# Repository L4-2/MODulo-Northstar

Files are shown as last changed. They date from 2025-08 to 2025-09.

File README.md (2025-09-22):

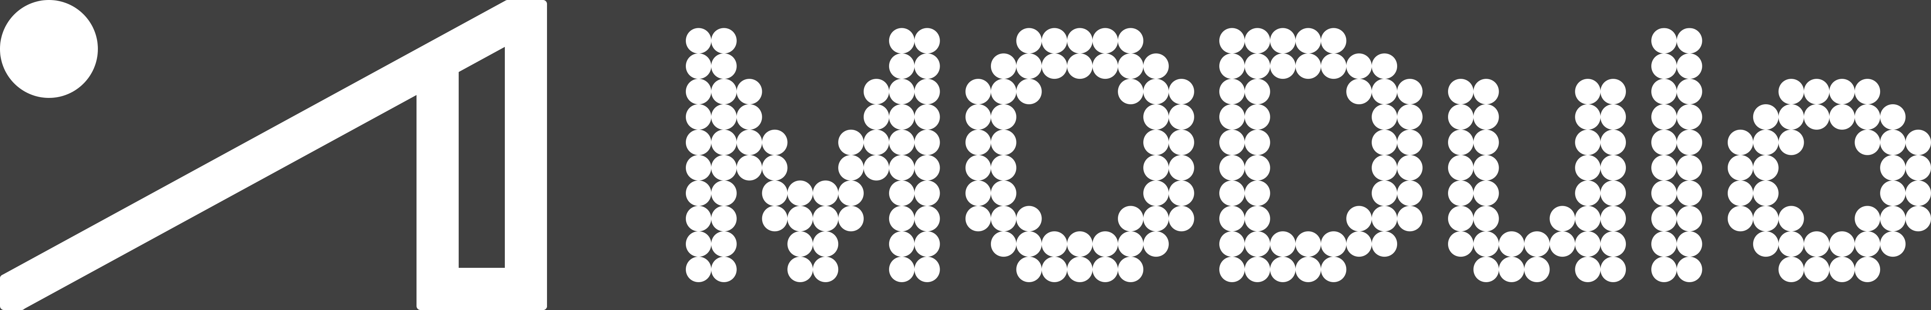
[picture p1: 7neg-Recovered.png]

##

## Authors

- [@L42](https://www.github.com/L4-2)

## License


# Northstar

This is the MODulo mouse development board. The Kicad project files are for Kicad 9.0 and above. You are free to use this design for your own use (non-commercial) as long as you credit here in some way.

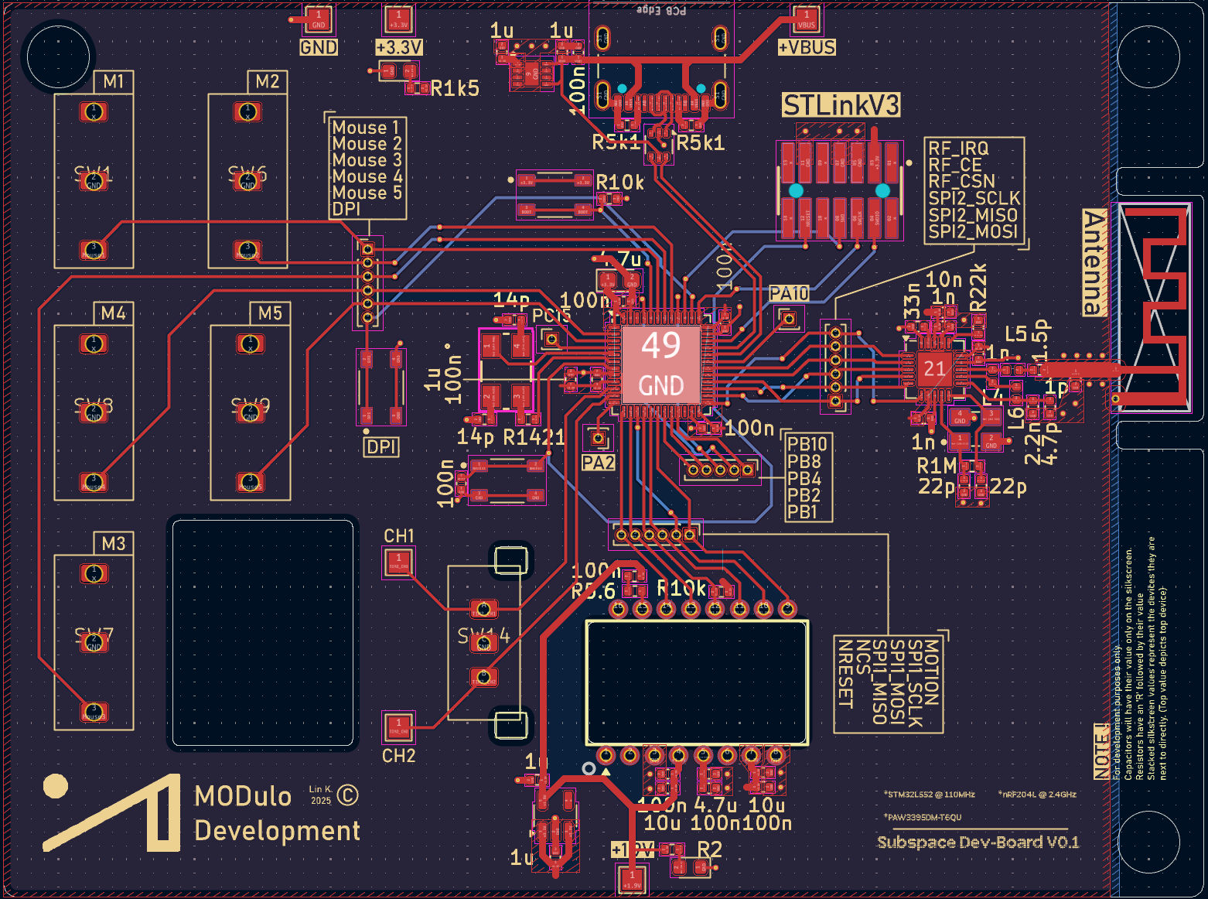
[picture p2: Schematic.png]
PCB


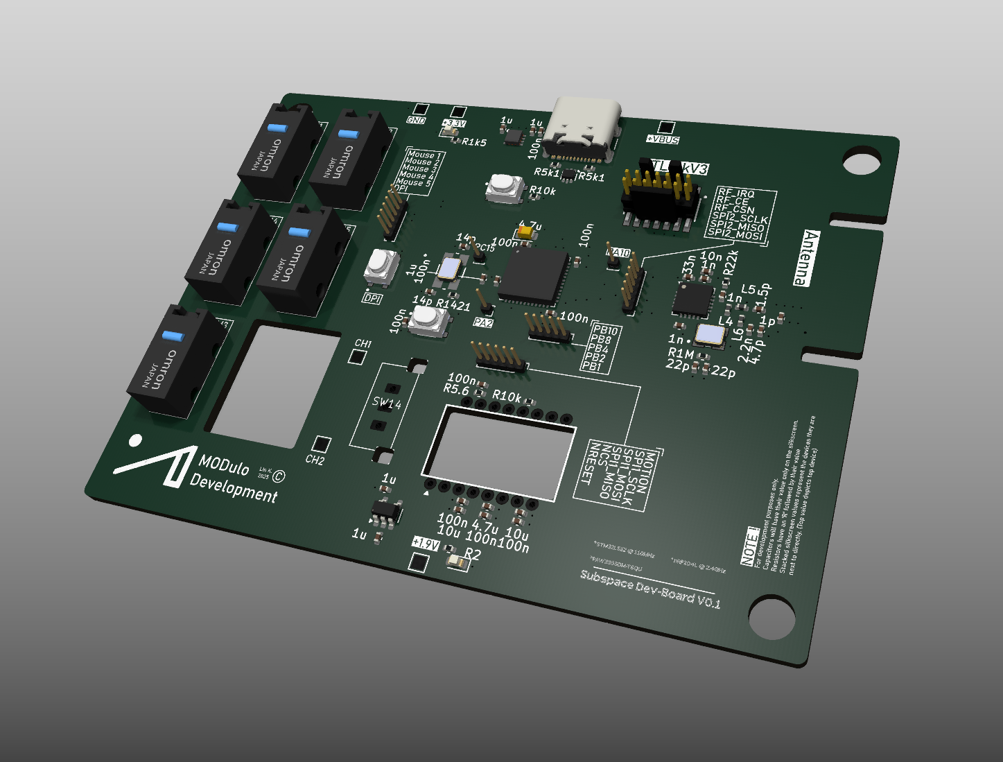
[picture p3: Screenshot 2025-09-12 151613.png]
3D Render


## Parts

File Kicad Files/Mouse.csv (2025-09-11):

Part Number* | Reference | Value | Datasheet | Footprint | Qty | DNP
CBR04C109C5GAC | C67 | 1p | ~ | Capacitor_SMD:C_0402_1005Metric | 1
CBR04C159C5GAC | C66 | 1.5p | ~ | Capacitor_SMD:C_0402_1005Metric | 1
CBR04C479C5GAC | C71 | 4.7p | ~ | Capacitor_SMD:C_0402_1005Metric | 1
04025U140FAT2A | C76,C78 | 14p | ~ | Capacitor_SMD:C_0402_1005Metric | 2
C0402C220K5GACTU | C61,C62 | 22p | ~ | Capacitor_SMD:C_0402_1005Metric | 2
C0402C102J5RACTU | C52,C54,C55 | 1n | ~ | Capacitor_SMD:C_0402_1005Metric | 3
C0402C222J5RACTUl | C70 | 2.2n | ~ | Capacitor_SMD:C_0402_1005Metric | 1
CHQ02-2N7J-RC | L6 | 2.7n | ~ | Inductor_SMD:L_0402_1005Metric | 1
WB0402T3N9SJ | L5 | 3.9n | ~ | Inductor_SMD:L_0402_1005Metric | 1
WB0402T8N2SJ | L4 | 8.2n | ~ | Inductor_SMD:L_0402_1005Metric | 1
C0402C103J3RACTU | C49 | 10n | ~ | Capacitor_SMD:C_0402_1005Metric | 1
C0402C333J4RACTU | C57 | 33n | ~ | Capacitor_SMD:C_0402_1005Metric | 1
C0402C104K4PACTU | C53,C58,C60,C65,C74,C75,C79,C80,C81,C82,C84,C89,C90,C91,C92 | 100n | ~ | Capacitor_SMD:C_0402_1005Metric | 15
GRM155R61E105KA12D | C8,C12,C15,C68,C83 | 1u | ~ | Capacitor_SMD:C_0402_1005Metric | 5
CC0402MRX5R6BB475,T491C106K016AT7280 | C59,C77 | 4.7u | ~ | Capacitor_SMD:C_0402_1005Metric,Capacitor_Tantalum_SMD:CP_EIA-2012-12_Kemet-R | 2
KAM05CT70E106KH | C56,C63 | 10u | ~ | Capacitor_SMD:C_0402_1005Metric | 2
AC0402FR-075R6L | R31 | 5.6 | ~ | Resistor_SMD:R_0402_1005Metric | 1
RN73R1ETTP1421B25 | R35 | 1421 | ~ | Resistor_SMD:R_0402_1005Metric | 1
RT0402BRE0710KL | R32,R36 | 10k | ~ | Resistor_SMD:R_0402_1005Metric | 2
ERA-2AEB223X | R20 | 22k | ~ | Resistor_SMD:R_0402_1005Metric | 1
RE0402BRE071ML | R27 | 1M | ~ | Resistor_SMD:R_0402_1005Metric | 1
ERA-2AEB512X | R41,R42 | 5k1 | ~ | Resistor_SMD:R_0402_1005Metric | 2
ECS-160-12-33Q-JES-TR | Y1 | ECS-160-12-33Q-JES-TR |  | ECS_160_12_33Q_JES_TR:XTAL_ECS-160-12-33Q-JES-TR | 1
ECS-80-12-30BQ-JES-TR | XTAL2 | ECS-80-12-30BQ-JES-TR | ECS-80-12-30BQ-JES-TR | ECS-80-12-30BQ-JES-TR:XTAL_ECS-80-12-30BQ-JES-TR | 1
FTSH-107-01-L-DV-K-A | J12 | FTSH-107-01-L-DV-K-A |  | FTSH_107_01_L_DV_K_A:SAMTEC_FTSH-107-01-L-DV-K-A | 1
nRF24L01P | U10 | nRF24L01P | http://www.nordicsemi.com/eng/content/download/2726/34069/file/nRF24L01P_Product_Specification_1_0.pdf | Package_DFN_QFN:QFN-20-1EP_4x4mm_P0.5mm_EP2.5x2.5mm | 1
SKRPABE010 | S1,S2,S3 | SKRPABE010 |  | SKRPABE010:SW_SKRPABE010 | 3
STM32L552CCU6 | U14 | STM32L552CEUxP | https://www.st.com/resource/en/datasheet/stm32l552ce.pdf | Package_DFN_QFN:QFN-48-1EP_7x7mm_P0.5mm_EP5.6x5.6mm | 1
TLV70019_SOT23-5 | U11 | TLV70019_SOT23-5 | http://www.ti.com/lit/ds/symlink/tlv700.pdf | Package_TO_SOT_SMD:SOT-23-5 | 1
TPS7A2133PQWDSGRQ1 | IC1 | TPS7A2133PQWDSGRQ1 | https://www.ti.com/lit/ds/symlink/tps7a21-q1.pdf | TPS7A2133PQWDSGRQ1:SON50P200X200X80-9N | 1
USB4105-GF-A | J4 | USB4105-GF-A | https://www.usb.org/sites/default/files/documents/usb_type-c.zip | Connector_USB:USB_C_Receptacle_GCT_USB4105-xx-A_16P_TopMnt_Horizontal | 1
USBLC6-2P6 | U8 | USBLC6-2P6 | https://www.st.com/resource/en/datasheet/usblc6-2.pdf | Package_TO_SOT_SMD:SOT-666 | 1

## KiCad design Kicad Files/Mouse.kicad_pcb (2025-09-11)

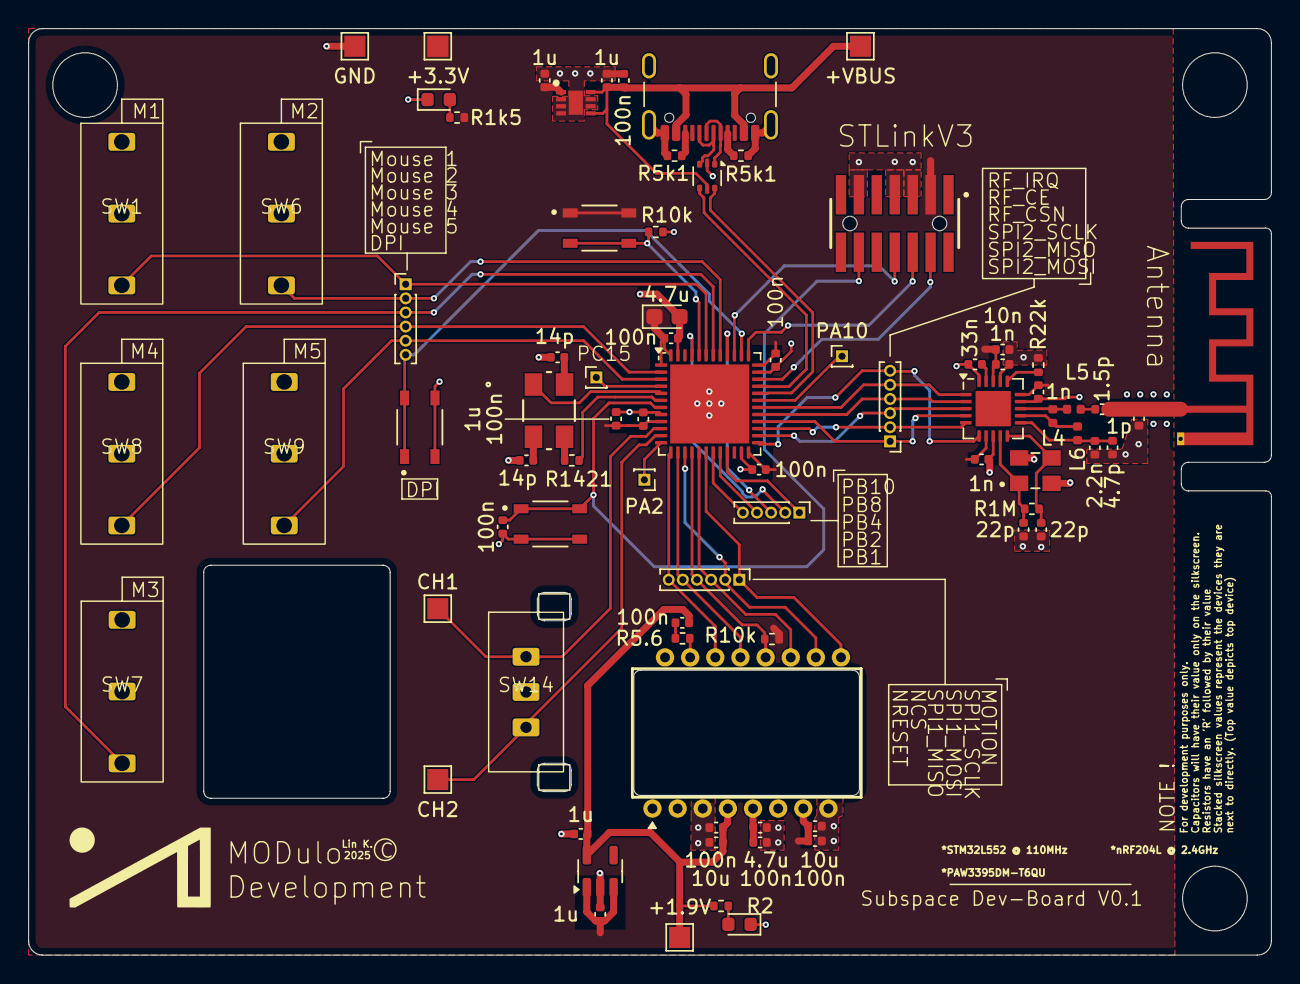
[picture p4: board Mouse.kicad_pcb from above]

Board: 2 copper layers, 88.0 x 65.6 mm, 80 parts (0 on the bottom side), 62 nets.

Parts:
1.5p: 1.5p; C_0402_1005Metric
1n, 1n#2, 1n#3: 1n; C_0402_1005Metric
1p: 1p; C_0402_1005Metric
1u, 1u#2, 1u#3, 1u#4, 1u#5: 1u; C_0402_1005Metric
2.2n: 2.2n; C_0402_1005Metric
4.7p: 4.7p; C_0402_1005Metric
4.7u: 4.7u; C_0402_1005Metric
4.7u#2: 4.7u; CP_EIA-2012-12_Kemet-R
10n: 10n; C_0402_1005Metric
10u, 10u#2: 10u; C_0402_1005Metric
14p, 14p#2: 14p; C_0402_1005Metric
22p, 22p#2: 22p; C_0402_1005Metric
33n: 33n; C_0402_1005Metric
100n, 100n#2, 100n#3, 100n#4, 100n#5, 100n#6, 100n#7, 100n#8, 100n#9, 100n#10: 100n; C_0402_1005Metric
 +3.3V : TestPoint; TestPoint_Pad_1.5x1.5mm
+1.9V: TestPoint; TestPoint_Pad_1.5x1.5mm
+VBUS: TestPoint; TestPoint_Pad_1.5x1.5mm
AE2: Antenna; Texas_SWRA117D_2.4GHz_Left
CH1, CH2: TestPoint; TestPoint_Pad_1.5x1.5mm
D1, D2: LED; LED_0603_1608Metric
GND: TestPoint; TestPoint_Pad_1.5x1.5mm
IC1: TPS7A2133PQWDSGRQ1; SON50P200X200X80-9N
J1, J2, J9: Conn_01x06_Pin; PinHeader_1x06_P1.00mm_Vertical
J3: Conn_01x05_Pin; PinHeader_1x05_P1.00mm_Vertical
J4: USB4105-GF-A; USB_C_Receptacle_GCT_USB4105-xx-A_16P_TopMnt_Horizontal
J8: Conn_01x01_Pin; PinHeader_1x01_P1.00mm_Vertical
J12: FTSH-107-01-L-DV-K-A; SAMTEC_FTSH-107-01-L-DV-K-A
L4: 8.2n; L_0402_1005Metric
L5: 3.9n; L_0402_1005Metric
L6: 2.7n; L_0402_1005Metric
PA2, PA10: Conn_01x01_Pin; PinHeader_1x01_P1.00mm_Vertical
R1M: 1M; R_0402_1005Metric
R1k5, R2: 1k5; R_0402_1005Metric
R5.6: 5.6; R_0402_1005Metric
R5k1, R5k1#2: 5k1; R_0402_1005Metric
R10k, R10k#2: 10k; R_0402_1005Metric
R22k: 22k; R_0402_1005Metric
R1421: 1421; R_0402_1005Metric
S1, S2, S3: SKRPABE010; SW_SKRPABE010
SW1, SW6, SW7, SW8, SW9: SW_Push_SPDT; Huano
SW14: RotaryEncoder
U8: USBLC6-2P6; SOT-666
U10: nRF24L01P; QFN-20-1EP_4x4mm_P0.5mm_EP2.5x2.5mm
U11: TLV70019_SOT23-5; SOT-23-5
U12: PMW3360DM-T2QU; PMW3360
U14: STM32L552CEUxP; QFN-48-1EP_7x7mm_P0.5mm_EP5.6x5.6mm
XTAL2: ECS-80-12-30BQ-JES-TR; ECS-80-12_ECS
Y1: ECS-160-12-33Q-JES-TR; XTAL_ECS-160-12-33Q-JES-TR

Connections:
+1.9V: 1u#4.1, 10u#2.1, 100n#4.1, 100n#5.1, +1.9V.1, R2.2, U11.5 (OUT), U12.4 (VDD)
+3.3V: 1n.1, 1n#2.1, 1n#3.1, 1u#2.1, 1u#3.1, 1u#5.1, 4.7u#2.1, 10n.1, 10u.1, 100n#2.1, 100n#6.1, 100n#7.1, 100n#8.1, 100n#10.1, +3.3V.1, IC1.1 (OUT_1), J12.03, R1k5.2, R10k#2.1, S3.1, S3.2, U10.7 (VDD), U10.15 (VDD), U10.18 (VDD), U11.1 (IN), U11.3 (EN), U12.7 (VDDIO), U14.1 (VBAT), U14.9 (VDDA), U14.24 (VDD), U14.36 (VDD), U14.48 (VDD)
/BOOT: R10k.2, S3.3, S3.4, U14.44 (PH3)
/DPI: J9.6, S1.1, S1.2, U14.38 (PA15)
/Mouse1: J9.1, SW1.3 (C), U14.43 (PB7)
/Mouse2: J9.2, SW6.3 (C), U14.41 (PB5)
/Mouse3: J9.3, SW7.3 (C), U14.42 (PB6)
/Mouse4: J9.4, SW8.3 (C), U14.2 (PC13)
/Mouse5: J9.5, SW9.3 (C), U14.3 (PC14)
/NRESET: 100n#9.2, J12.12, S2.1, S2.2, U14.7 (NRST)
/RF_CE: J2.5, U10.1 (CE), U14.30 (PA9)
/RF_CSN: J2.4, U10.2 (CSN), U14.29 (PA8)
/RF_IRQ: J2.6, U10.6 (IRQ), U14.25 (PB12)
/SENSOR_MOTION: J1.1, U12.9 (MOTION), U14.18 (PB0)
/SENSOR_NCS: J1.5, U12.13 (NCS), U14.14 (PA4)
/SENSOR_NRESET: J1.6, U12.14 (NRESET), U14.13 (PA3)
/SPI1_MISO: J1.4, R10k#2.2, U12.12 (MISO), U14.16 (PA6)
/SPI1_MOSI: J1.3, U12.11 (MOSI), U14.17 (PA7)
/SPI1_SCLK: J1.2, U12.10 (SCLK), U14.15 (PA5)
/SPI2_MISO: J2.2, U10.5 (MISO), U14.27 (PB14)
/SPI2_MOSI: J2.1, U10.4 (MOSI), U14.28 (PB15)
/SPI2_SCLK: J2.3, U10.3 (SCK), U14.26 (PB13)
/SWCLK: J12.06, U14.37 (PA14)
/SWDIO: J12.04, U14.34 (PA13)
/SWO: J12.08, U14.39 (PB3)
/TIM2_CH1: CH1.1, SW14.A, U14.10 (PA0)
/TIM2_CH2: CH2.1, SW14.B, U14.11 (PA1)
/USB_DN: U8.6 (I/O1), U14.32 (PA11)
/USB_DP: U8.4 (I/O2), U14.33 (PA12)
GND: 1n.2, 1n#2.2, 1n#3.2, 1p.2, 1u.2, 1u#2.2, 1u#3.2, 1u#4.2, 1u#5.2, 2.2n.2, 4.7p.2, 4.7u.2, 4.7u#2.2, 10n.2, 10u.2, 10u#2.2, 14p.2, 14p#2.2, 22p.2, 22p#2.2, 33n.2, 100n.2, 100n#2.2, 100n#3.2, 100n#5.2, 100n#6.2, 100n#7.2, 100n#8.2, 100n#9.1, 100n#10.2, D1.1 (K), D2.1 (K), GND.1, IC1.2 (OUT_2), IC1.3 (NC_1), IC1.4 (GND), IC1.6 (NC_2), IC1.7 (IN_1), IC1.9 (EP), J4.A1 (GND), J4.A12 (GND), J4.B1 (GND), J4.B12 (GND), J4.S1 (SHIELD), J12.05, J12.07, J12.11, R5k1.1, R5k1#2.1, R10k.1, R22k.2, S1.3, S1.4, S2.3, S2.4, SW1.2 (B), SW6.2 (B), SW7.2 (B), SW8.2 (B), SW9.2 (B), SW14.C, U8.2 (GND), U10.8 (VSS), U10.14 (VSS), U10.17 (VSS), U10.20 (VSS), U11.2 (GND), U12.3 (GND), U12.8 (GNDIO), U14.8 (VSSA), U14.23 (VSS), U14.35 (VSS), U14.47 (VSS), U14.49 (VSS), Y1.2 (GND), Y1.4 (GND__1)
unnamed: 1.5p.2, 1p.1, AE2.1 (A)
unnamed: 1.5p.1, L5.2
unnamed: 100n#4.2, R5.6.2
unnamed: 14p#2.1, XTAL2.4
unnamed: 14p.1, XTAL2.2
unnamed: D1.2 (A), R1k5.1
unnamed: D2.2 (A), R2.1
unnamed: J3.1, U14.21 (PB10)
unnamed: J3.2, U14.45 (PB8)
unnamed: J3.3, U14.40 (PB4)
unnamed: J3.4, U14.20 (PB2)
unnamed: J3.5, U14.19 (PB1)
unnamed: J4.A5 (CC1), R5k1.2
unnamed: J4.B5 (CC2), R5k1#2.2
unnamed: J4.A6 (D+), J4.B6 (D+), U8.3 (I/O2)
unnamed: J4.A7 (D-), J4.B7 (D-), U8.1 (I/O1)
unnamed: J8.1, U14.4 (PC15)
unnamed: PA10.1, U14.31 (PA10)
unnamed: PA2.1, U14.12 (PA2)
unnamed: R1421.2, XTAL2.3
unnamed: L4.2, L6.1, U10.12 (ANT1)
unnamed: L4.1, L5.1, U10.13 (ANT2)
unnamed: 33n.1, U10.19 (DVDD)
unnamed: R22k.1, U10.16 (IREF)
unnamed: 2.2n.1, 4.7p.1, L6.2, U10.11 (VDD_PA)
unnamed: 22p.1, R1M.2, U10.10 (XC1), Y1.3 (OUT/IN)
unnamed: 22p#2.1, R1M.1, U10.9 (XC2), Y1.1 (IN/OUT)
unnamed: R5.6.1, U12.15 (LED_P)
unnamed: 4.7u.1, 100n#3.1, U12.5 (VDDREG)
unnamed: U14.5 (PH0), XTAL2.1
unnamed: R1421.1, U14.6 (PH1)
VBUS: 1u.1, 100n.1, +VBUS.1, IC1.5 (EN), IC1.8 (IN_2), J4.A4 (VBUS), J4.A9 (VBUS), J4.B4 (VBUS), J4.B9 (VBUS), U8.5 (VBUS)

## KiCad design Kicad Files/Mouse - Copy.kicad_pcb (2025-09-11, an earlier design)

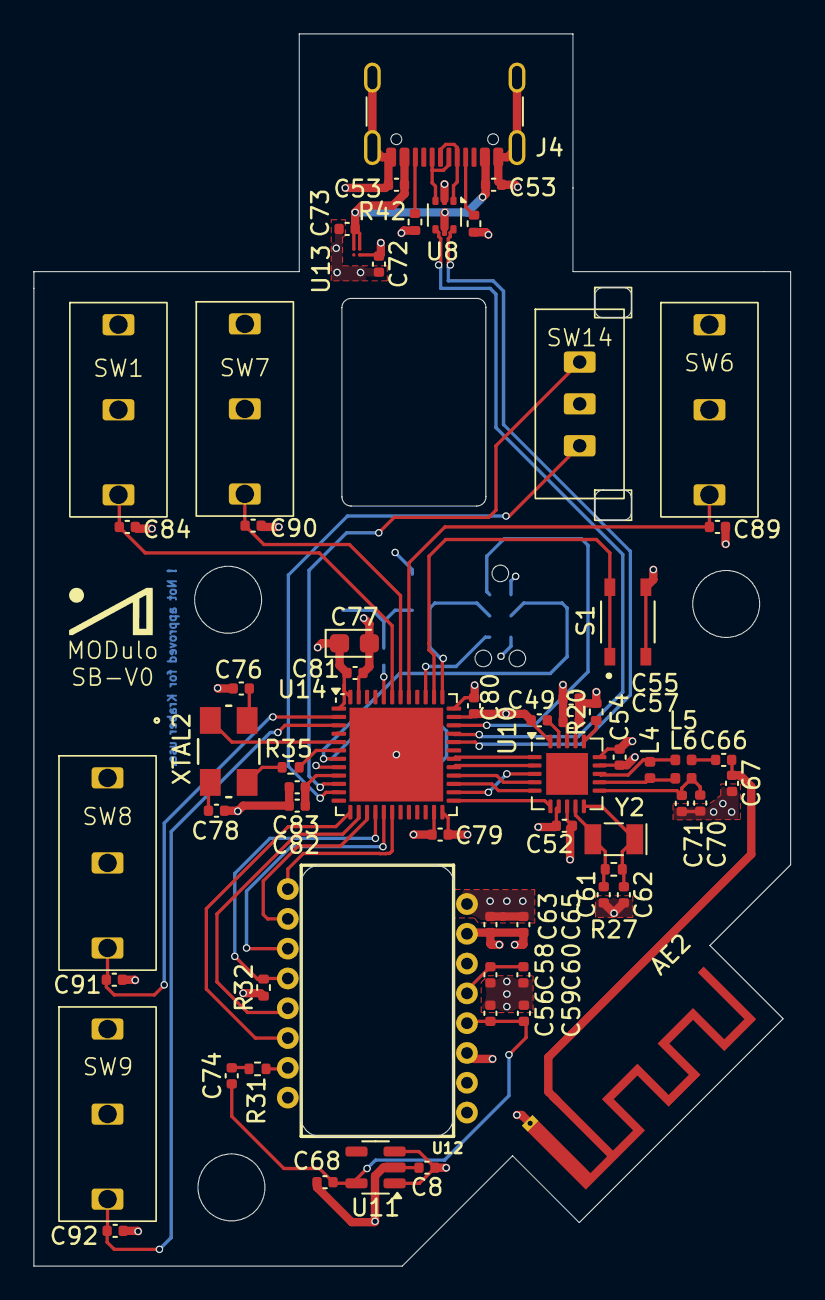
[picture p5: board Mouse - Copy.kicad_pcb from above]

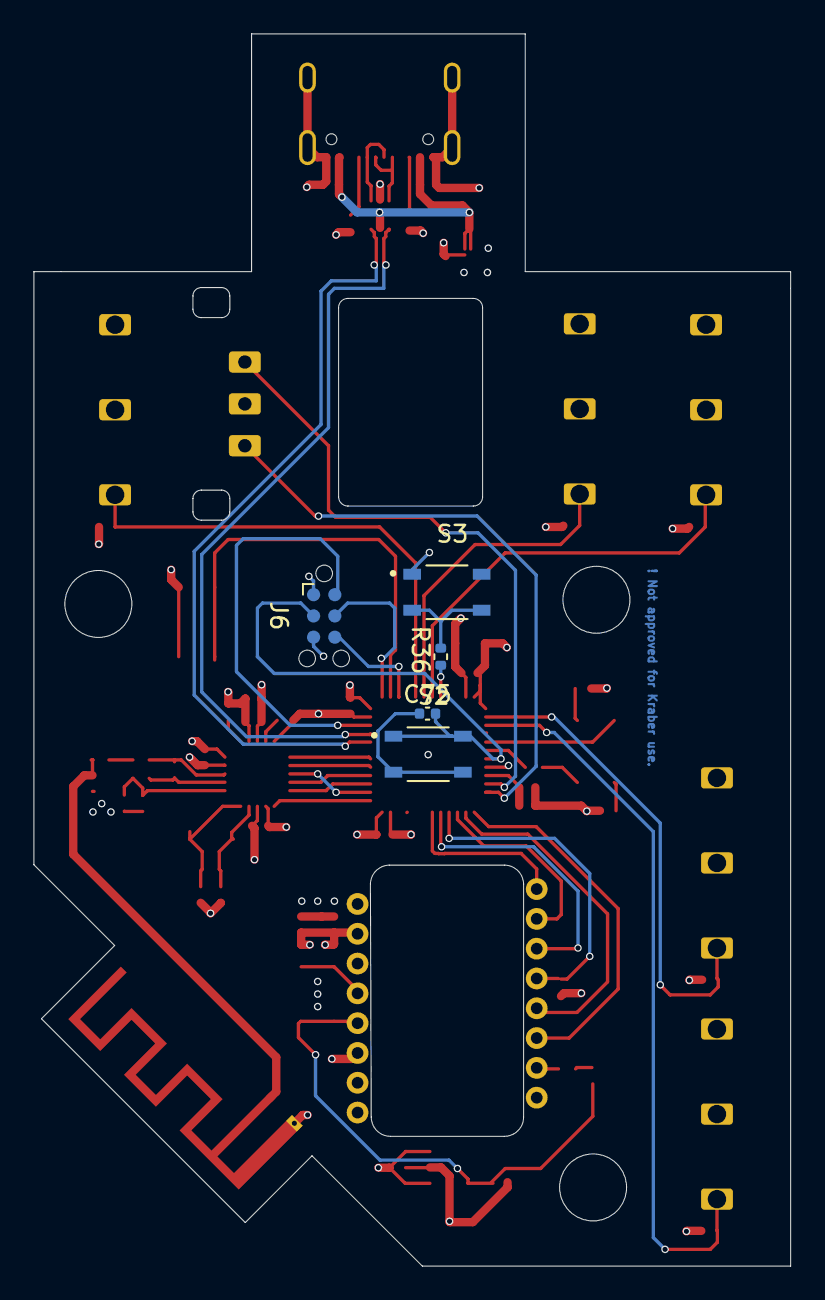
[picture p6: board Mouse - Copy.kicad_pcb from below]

Board: 4 copper layers, 45.2 x 73.6 mm, 69 parts (5 on the bottom side), 52 nets.

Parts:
AE2: Antenna; Texas_SWRA117D_2.4GHz_Left
C8, C68, C72, C73, C83: 1u; C_0402_1005Metric
C49: 10n; C_0402_1005Metric
C52, C54, C55: 1n; C_0402_1005Metric
C53, C53#2, C58, C60, C65, C74, C75, C79, C80, C81, C82, C84, C89, C90, C91, C92: 100n; C_0402_1005Metric
C56, C63: 10u; C_0402_1005Metric
C57: 33n; C_0402_1005Metric
C59: 4.7u; C_0402_1005Metric
C61, C62: 22p; C_0402_1005Metric
C66: 1.5p; C_0402_1005Metric
C67: 1p; C_0402_1005Metric
C70: 2.2n; C_0402_1005Metric
C71: 4.7n; C_0402_1005Metric
C76, C78: 14p; C_0402_1005Metric
C77: 4.7u; CP_EIA-2012-12_Kemet-R
J4: USB_C_Receptacle_USB2.0_14P; USB_C_Receptacle_GCT_USB4105-xx-A_16P_TopMnt_Horizontal
J6: Conn_ARM_SWD_TagConnect_TC2030; Tag-Connect_TC2030-IDC-NL_2x03_P1.27mm_Vertical
L4: 8.2n; L_0402_1005Metric
L5: 3.9n; L_0402_1005Metric
L6: 2.7n; L_0402_1005Metric
R20: 22k; R_0402_1005Metric
R27: 1M; R_0402_1005Metric
R31: 5.6; R_0402_1005Metric
R32, R36: 10k; R_0402_1005Metric
R35: 1421; R_0402_1005Metric
R41, R42: 5k1; R_0402_1005Metric
S1, S2, S3: SKRPABE010; SW_SKRPABE010
SW1, SW6, SW7, SW8, SW9: SW_Push_SPDT; Huano
SW14: RotaryEncoder
U8: USBLC6-2P6; SOT-666
U10: nRF24L01P; QFN-20-1EP_4x4mm_P0.5mm_EP2.5x2.5mm
U11: TLV70019_SOT23-5; SOT-23-5
U12: PMW3360DM-T2QU; PMW3360
U13: NCP161BFCS330T2G; WLCSP4_P6XP6_ONS
U14: STM32L552CEUxP; QFN-48-1EP_7x7mm_P0.5mm_EP5.6x5.6mm
XTAL2: ECS-80-12-30BQ-JES-TR; ECS-80-12_ECS
Y2: Crystal; Crystal_SMD_MicroCrystal_CC7V-T1A-2Pin_3.2x1.5mm

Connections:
+1.9V: C56.1, C58.1, C68.1, C74.1, U11.5 (OUT), U12.4 (VDD)
+3.3V: C8.1, C49.1, C52.1, C54.1, C55.1, C63.1, C65.1, C72.1, C77.1, C79.1, C80.1, C81.1, C82.1, C83.1, J6.1 (VCC), R32.1, S3.1, S3.2, U10.7 (VDD), U10.15 (VDD), U10.18 (VDD), U11.1 (IN), U11.3 (EN), U12.7 (VDDIO), U13.A2 (OUT), U14.1 (VBAT), U14.9 (VDDA), U14.24 (VDD), U14.36 (VDD), U14.48 (VDD)
/BOOT: R36.2, S3.3, S3.4, U14.44 (PH3)
/DPI: S1.1, S1.2, U14.38 (PA15)
/Mouse1: C84.1, SW1.3 (C), U14.43 (PB7)
/Mouse2: C89.1, SW6.3 (C), U14.41 (PB5)
/Mouse3: C90.1, SW7.3 (C), U14.42 (PB6)
/Mouse4: C91.1, SW8.3 (C), U14.2 (PC13)
/Mouse5: C92.1, SW9.3 (C), U14.3 (PC14)
/NRESET: C75.2, J6.3 (~RESET), S2.1, S2.2, U14.7 (NRST)
/RF_CE: U10.1 (CE), U14.30 (PA9)
/RF_CSN: U10.2 (CSN), U14.29 (PA8)
/RF_IRQ: U10.6 (IRQ), U14.25 (PB12)
/SENSOR_MOTION: U12.9 (MOTION), U14.18 (PB0)
/SENSOR_NCS: U12.13 (NCS), U14.14 (PA4)
/SENSOR_NRESET: U12.14 (NRESET), U14.13 (PA3)
/SPI1_MISO: R32.2, U12.12 (MISO), U14.16 (PA6)
/SPI1_MOSI: U12.11 (MOSI), U14.17 (PA7)
/SPI1_SCLK: U12.10 (SCLK), U14.15 (PA5)
/SPI2_MISO: U10.5 (MISO), U14.27 (PB14)
/SPI2_MOSI: U10.4 (MOSI), U14.28 (PB15)
/SPI2_SCLK: U10.3 (SCK), U14.26 (PB13)
/SWCLK: J6.4 (SWCLK), U14.37 (PA14)
/SWDIO: J6.2 (SWDIO), U14.34 (PA13)
/SWO: J6.6 (SWO), U14.39 (PB3)
/TIM2_CH1: SW14.A, U14.10 (PA0)
/TIM2_CH2: SW14.B, U14.11 (PA1)
/USB_DN: U8.6 (I/O1), U14.32 (PA11)
/USB_DP: U8.4 (I/O2), U14.33 (PA12)
GND: C8.2, C49.2, C52.2, C53.2, C53#2.2, C54.2, C55.2, C56.2, C57.2, C58.2, C59.2, C60.2, C61.2, C62.2, C63.2, C65.2, C67.2, C68.2, C70.2, C71.2, C72.2, C73.2, C75.1, C76.2, C77.2, C78.2, C79.2, C80.2, C81.2, C82.2, C83.2, C84.2, C89.2, C90.2, C91.2, C92.2, J4.A1 (GND), J4.A12 (GND), J4.B1 (GND), J4.B12 (GND), J4.S1 (SHIELD), J6.5 (GND), R20.2, R36.1, R41.1, R42.1, S1.3, S1.4, S2.3, S2.4, SW1.2 (B), SW6.2 (B), SW7.2 (B), SW8.2 (B), SW9.2 (B), SW14.C, U8.2 (GND), U10.8 (VSS), U10.14 (VSS), U10.17 (VSS), U10.20 (VSS), U11.2 (GND), U12.3 (GND), U12.8 (GNDIO), U13.B2 (GND), U14.8 (VSSA), U14.23 (VSS), U14.35 (VSS), U14.47 (VSS), U14.49 (VSS)
unnamed: AE2.1 (A), C66.2, C67.1
unnamed: C66.1, L5.2
unnamed: C74.2, R31.2
unnamed: C76.1, XTAL2.4
unnamed: C78.1, XTAL2.2
unnamed: J4.A5 (CC1), R42.2
unnamed: J4.B5 (CC2), R41.2
unnamed: J4.A6 (D+), J4.B6 (D+), U8.3 (I/O2)
unnamed: J4.A7 (D-), J4.B7 (D-), U8.1 (I/O1)
unnamed: R35.2, XTAL2.3
unnamed: L4.2, L6.1, U10.12 (ANT1)
unnamed: L4.1, L5.1, U10.13 (ANT2)
unnamed: C57.1, U10.19 (DVDD)
unnamed: R20.1, U10.16 (IREF)
unnamed: C70.1, C71.1, L6.2, U10.11 (VDD_PA)
unnamed: C62.1, R27.2, U10.10 (XC1), Y2.1
unnamed: C61.1, R27.1, U10.9 (XC2), Y2.2
unnamed: R31.1, U12.15 (LED_P)
unnamed: C59.1, C60.1, U12.5 (VDDREG)
unnamed: U14.5 (PH0), XTAL2.1
unnamed: R35.1, U14.6 (PH1)
VBUS: C53.1, C53#2.1, C73.1, J4.A4 (VBUS), J4.A9 (VBUS), J4.B4 (VBUS), J4.B9 (VBUS), U8.5 (VBUS), U13.A1 (IN), U13.B1 (EN)

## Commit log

2025-09-11 Kicad project files
    [Mouse - Copy.kicad_pcb, Mouse.csv, Mouse.kicad_pcb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]
2025-09-22 Rename Screenshot 2025-08-27 215550.png to Schematic.png

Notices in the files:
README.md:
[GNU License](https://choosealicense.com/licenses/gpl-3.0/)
